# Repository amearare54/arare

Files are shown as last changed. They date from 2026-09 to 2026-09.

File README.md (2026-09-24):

<p align="center">
  <picture>
    <source media="(prefers-color-scheme: dark)" srcset="docs/readme-logo-white.png">
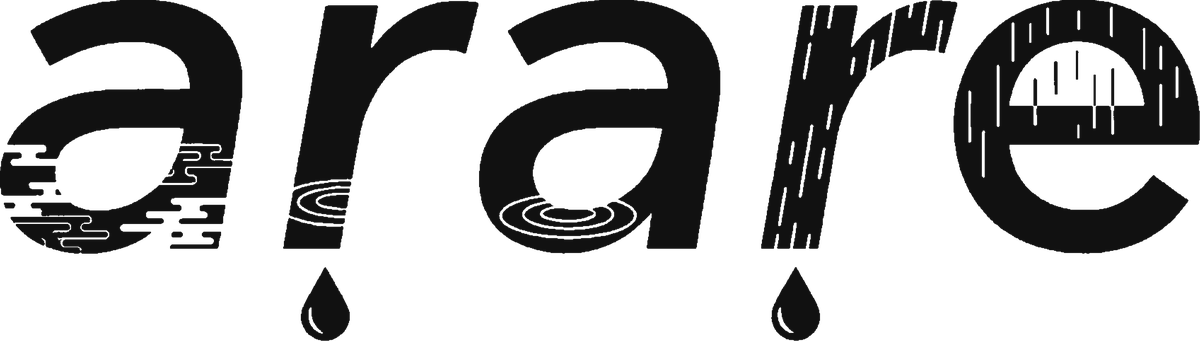
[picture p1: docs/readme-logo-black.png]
arare
    
  </picture>
</p>

<p align="center">
  左右分割・完全無線のロープロファイルキーボードです。<br>
  右手にトラックボール、左手にスティックを載せていて、<br>
  ホームポジションから手を大きく動かさないまま、打つ・指す・回すができます。
</p>

<p align="center">
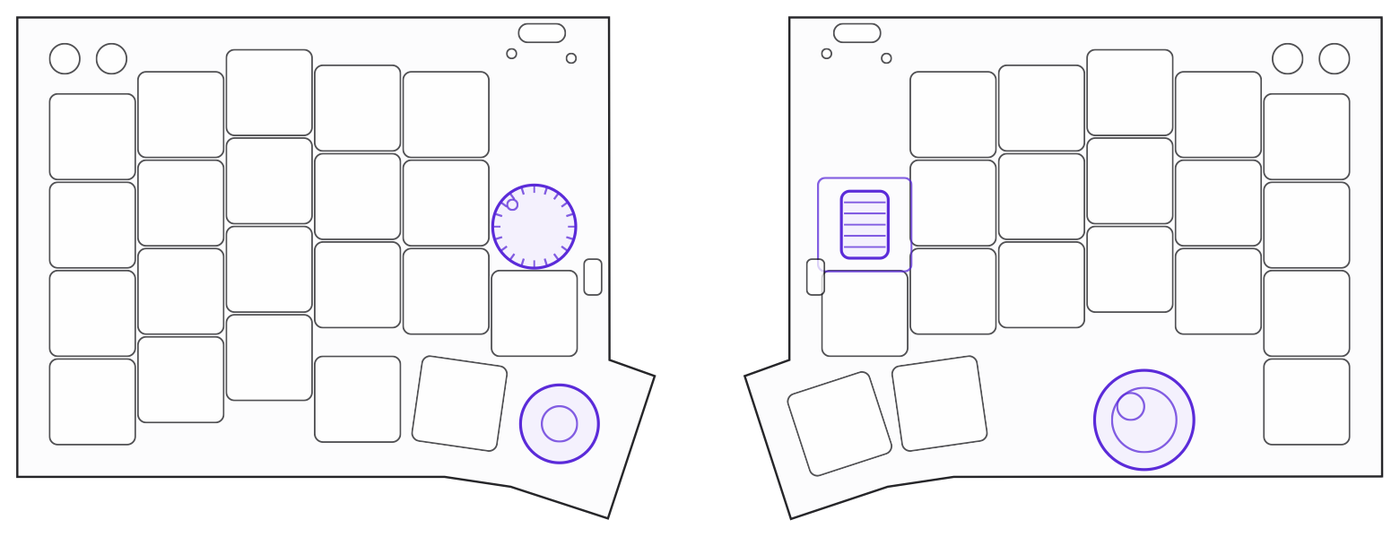
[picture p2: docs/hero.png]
arare 本体を上から見た図。左手側にノブとスティック、右手側にホイールとトラックボール
  
</p>

## 取扱説明書・カラーシミュレーター・arare Studio

ブラウザで開くだけの3つのページです。**アカウント登録もインストールも要りません。実機が手元になくても開けます。**

<div align="center">
<table>
<tr>
<td align="center" width="33%">
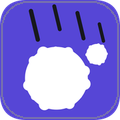
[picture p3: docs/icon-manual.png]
<br>
<a href="https://amearare54.github.io/arare/manual.html"><b>MANUAL</b></a><br>
どんなキーボードか知る
</td>
<td align="center" width="33%">
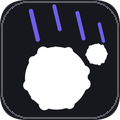
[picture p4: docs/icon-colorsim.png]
<br>
<a href="https://amearare54.github.io/arare/colorsim.html"><b>COLOR SIMULATOR</b></a><br>
色を決めるとき
</td>
<td align="center" width="33%">
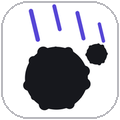
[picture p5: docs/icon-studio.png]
<br>
<a href="https://amearare54.github.io/arare/"><b>STUDIO</b></a><br>
キーを変えたくなったら
</td>
</tr>
</table>
</div>

> [!TIP]
> リンクが開けないときは、こちらから直接どうぞ。
> MANUAL <https://amearare54.github.io/arare/manual.html> ／
> COLOR SIMULATOR <https://amearare54.github.io/arare/colorsim.html> ／
> STUDIO <https://amearare54.github.io/arare/>
>
> arare Studio で実機につないで書き換える機能だけ、Chrome / Edge が必要です。
> 取扱説明書は開いたときに短い演出（4.6秒）が流れますが、クリックなどでいつでも飛ばせます。

ZMK の設定・ピン割当・ビルドを見に来た方は [技術情報](#技術情報) へどうぞ。

## arare でできること

| | できること |
|---|---|
| 右手・トラックボール | &#216;19 mm の光学センサー式。指で転がしてポインタを動かします。 |
| 右手・ホイール | 軸は左右方向で、前後に転がします（マウスのスクロールホイールと同じ向き）。出荷時は回すとページ送り、押し込みで ⌘V（貼り付け）。 |
| 左手・ノブ | 軸は上向きで、ボリュームつまみのように水平に回します。出荷時は回すと拡大 / 縮小（⌘+ / ⌘-）、押し込みで &#8679;&#8984;V。 |
| 左手・スティック | トラックパッドの代わりとして載せています。2 本指・3 本指でするような操作を、親指ひとつでできるように、というつもりです。倒すとその向きのショートカットが出ます（出荷時は Mission Control とデスクトップの移動＝トラックパッドの 3 本指スワイプと同じ操作）。カーソルはトラックボールの担当です。押し込んでいるあいだは L3 レイヤーになります。 |
| 完全無線 | 左右それぞれに電池とマイコンがあり、間をつなぐケーブルがありません。残量はマイコンのランプが色で知らせます。 |
| ホットスワップ | Kailh Choc v2 互換のキースイッチを、はんだ付けなしで差し替えられます。 |
| キーマップ | ブラウザから何度でも変えられます（[arare Studio](https://amearare54.github.io/arare/)）。 |

## まず見てほしいもの

**1. 大きさと各部を見る** → [取扱説明書の「各部の名称」](https://amearare54.github.io/arare/manual.html#parts)

平面図・側面図・正面図に寸法を入れた総組立図を載せています。コンセプト、はじめかた、出荷時のキーマップ、名前の由来、仕様・お手入れ・安全にお使いいただくために、なども入っています。

**2. 色を決める** → [カラーシミュレーターを開く](https://amearare54.github.io/arare/colorsim.html)

ケースは3Dプリントなので、部品ごとに色を選べます。実機と同じ3Dデータをブラウザに載せていて、クリア樹脂の見えかたも再現します。EXPLODE で分解図、AUTO でゆっくり回しながら確かめられます。

**3. キー配列を見る** → [arare Studio を開く](https://amearare54.github.io/arare/)

実機がなくても、配置図の上でキーの割り当てを触ってみられます。

## 使いはじめる

1. **電源を入れる** — 左右それぞれの側面にあるスライドスイッチを内側（ON）へ。左右とも忘れずに。
2. **パソコンとつなぐ** — Bluetooth の一覧から `arare` を選びます。一覧に出るのは右手側だけで、左手側は右手側と自動でつながります。
3. **キーの割り当てを変える** — 書き換える前に、右手の外側のタクトスイッチ（UNLOCK）を一回押します。→ [arare Studio](https://amearare54.github.io/arare/)

### ランプの見かた

USB-C のとなりに、同じ大きさの小さな穴が2つあります。片方がマイコン基板のリセットスイッチ、もう片方がランプです（どちらがどちらかは [取扱説明書の各部の名称](https://amearare54.github.io/arare/manual.html#parts) の図で確かめられます）。

ランプは電池残量を色で知らせます。ふだんは消えています。

| 色 | 残量 |
|---|---|
| 緑 | 60 % 以上 |
| 橙 | 20 % より上、60 % 未満 |
| 赤 | 20 % 以下 |

電源を入れたときと、しばらく置いてから使いはじめたときに 1.5 秒だけ点きます。残量が 20 % 以下になると赤く2回点滅して以降5分ごと、10 % 以下になると赤く3回点滅して以降2分ごとに知らせます。**点滅するのは使っているあいだだけで、置きっぱなしのときと充電中は光りません。** USB-C をつないでいるあいだは、残量の色が点いたままになります。

> [!TIP]
> つながらないとき、充電のしかた、接続先の切り替えは、[取扱説明書の「はじめかた」](https://amearare54.github.io/arare/manual.html#start) にまとめています。

## 仕様

| 項目 | 内容 |
|---|---|
| 方式 | 左右分割・Bluetooth LE 接続（ZMK ファームウェア） |
| キー数 | 実キー40（左21／右19）＋エンコーダー押し込み2／スティック押し込み1／タクトスイッチ4（計47ポジション） |
| 本体サイズ | 片手あたり 122.1 &#215; 96.1 mm ／ 高さ 23.8 mm（右）・28.1 mm（左・ノブ含む） |
| キーピッチ | 17 &#215; 17 mm |
| キースイッチ | Kailh Choc v2 互換・ホットスワップ |
| ポインティング | 19 mm トラックボール（光学センサー・PAW3222）／ TMR 磁気式スティック |
| ロータリー | 縦型ノブ（左・水平に回す）／ 横型ホイール（右・前後に転がす）各1、押し込み付き |
| マイコン | Seeed XIAO nRF52840 &#215;2（技適取得済みモジュール・central は右手） |
| 電源 | リチウムポリマー電池（左右各1）／ USB-C 充電 |
| ケース | 3Dプリント・ガスケットマウント構造 |
| 対応 | Bluetooth LE キーボードとして動作する機器（macOS / Windows / iOS / iPadOS / Android など） |
| 編集ツール | arare Studio（ブラウザ）／ ZMK Studio 互換 |

## このリポジトリにあるもの

| もの | 場所 | 条件 |
|---|---|---|
| 3つのページの実体 | [`docs/`](docs/) | 公開 |
| ファームウェア（ZMK設定） | [`config/`](config/) | 公開 |
| 電池残量ランプの自前モジュール | [`src/battery_led.c`](src/battery_led.c) / [`Kconfig`](Kconfig) / [`CMakeLists.txt`](CMakeLists.txt) | 公開 |
| ケース・プレート・ノブ等の3Dプリントデータ | [`model/case/`](model/case/) | 個人使用のみ |
| ロゴ（SVG / PNG / DXF / STL） | [`model/logo/`](model/logo/) | 個人使用のみ |

> [!IMPORTANT]
> `model/` の3Dデータとロゴは、個人使用のみにとどめてください。再配布・商用利用はご遠慮ください（→ [model/README.md](model/README.md)）。
> カラーシミュレーターに埋め込まれている3Dデータも同じ条件です。

**まだ公開していないもの**

- 基板データ（KiCad / ガーバー）
- キーキャップの3Dデータ

基板データが非公開のため、ここに公開しているデータだけで1台を組み上げることはできません。

**これからやること**

- DYA Studio のフル対応
- 深いスリープ（現在は無効）

理由は [技術情報](#技術情報)の「いまできないこと」に書いています。

## 技術情報

- ZMK v0.3.0 / ボードは `seeeduino_xiao_ble` &#215;2、central = 右手
- マトリクスは charlieplex 6線
- トラックボールは PAW3222。ドライバは sekigon-gonnoc/zmk-driver-paw3222（torabo-tsuki ブランチ）
- ZMK Studio 対応（central = 右手に USB 接続して <https://zmk.studio/> でも使えます）。タクトSW は左外側・左内側・右内側＝Bluetooth の接続先 1〜3、右外側＝アンロック
- ピン割当とマトリクス定義は、非公開の基板データ（KiCad）と機械照合しています

### ビルドと書き込み

1. push すると GitHub Actions がビルドします（`arare_R`＝Studio snippet 付き / `arare_L` / `settings_reset`）
2. Actions の Artifacts から UF2 をダウンロードします
3. XIAO を BOOT モード（リセット2度押し）にすると、USB ドライブとして見えます
4. UF2 をそこにコピーすると書き込まれます

書き込みは左右それぞれに必要です。

> [!WARNING]
> 設定がおかしくなったときは、左右それぞれに `settings_reset` を書き込んでから、`arare_R` / `arare_L` を書き直してください。`settings_reset` を書き込んだままではキーボードとして動きません。

<details>
<summary>ピン割当とマトリクス</summary>

| | 左手 (peripheral) | 右手 (**central**) |
|---|---|---|
| ボード | seeeduino_xiao_ble | seeeduino_xiao_ble |
| マトリクス | charlieplex 6線 (M0=D0 M1=D1 M2=D6 M3=D7 M4=D8 M5=D9) | charlieplex 6線 (M0..M5=D0..D5) |
| エンコーダ | EC12縦 (D2/D3) 押込=Shift+Cmd+V | CKW12横 (D6/D7) 押込=Cmd+V |
| ポインタ | スティック アナログXY (AIN2/AIN3)＝ジェスチャー専用（右手の `joy_gesture` が処理）＋ 押込=D10直結キー（`&mo 3`） | PAW3222 (spi1: SCK=P1.13 SDIO=P1.14 CS=P1.15 MOTION=P0.09) |

スティックのアナログXYは `CONFIG_ZMK_BATTERY_REPORTING` と SAADC を取り合います。ZMK 本体の電池ドライバは oversampling=4 が固定で、併用すると SAADC が止まります。`arare_saadc_fix.dtsi` が本体の `&vbatt` を無効にし、oversampling=0 の arare 版ノードへ `zmk,battery` を向け替えることで両立させています（`arare_tuning_L.dtsi` から include）。

電池残量ランプは `CONFIG_ARARE_BATTERY_LED` で有効にする自前モジュールです（`zephyr/module.yml` から `Kconfig` と `CMakeLists.txt` を読み込み、`src/battery_led.c` をビルドします）。しきい値・点灯時間・警告間隔は `Kconfig` で変えられます。

</details>

<details>
<summary>いまできないこと（フェーズ2・既知の制約）</summary>

- **DYA Studio フル対応**: キーマップ編集は公式 ZMK Studio 対応のまま DYA Studio からも使えます。トラックボール調整等のフル機能には cormoran/zmk フォーク＋モジュール4点が必要です（experimental 宣言あり）。
- **深いスリープ（`CONFIG_ZMK_SLEEP`）**: charlieplex が割込を持てず復帰不能なため、無効のままです。電源は物理スイッチで切ります。

</details>

## 名前のこと

「感謝感激雨あられ」の **あられ** から取りました。世に出ている良いキーボードの設計を参考にさせていただいたことへの**感謝**と、使ってくださる方に**感激**してほしいという願いを、そのまま名前にしています。

ロゴの文字には、和の気象の意匠が彫ってあります。霞・雨・波紋・しずく。遠目にはただの文字ですが、近づくと天気が見えてきます。表記は小文字の arare で通しています。

## 利用条件

- `config/` `src/` `Kconfig` `CMakeLists.txt` `zephyr/` のファームウェアと `docs/` のページ … 公開しています。参照や、ご自身の arare 用のビルドにお使いいただけます
- `model/case/` `model/logo/` の3Dデータとロゴ … 個人使用のみ。再配布・商用利用はご遠慮ください（→ [model/README.md](model/README.md)）
- 基板データ（KiCad / ガーバー）、キーキャップの3Dデータ … 非公開です

気づいたことや質問は Issues へどうぞ。

---

<p align="center">
  <a href="https://amearare54.github.io/arare/manual.html">MANUAL</a> ・
  <a href="https://amearare54.github.io/arare/colorsim.html">COLOR SIMULATOR</a> ・
  <a href="https://amearare54.github.io/arare/">STUDIO</a>
</p>

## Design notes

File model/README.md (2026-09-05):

> [!CAUTION]
> ここに公開している3Dデータは個人使用のみにとどめてください。
> 再配布・商用利用はご遠慮ください。

# arare 3Dプリントデータ

ケース・プレート・ノブ等の3Dデータです。**基板データ（KiCad/ガーバー）とキーキャップは非公開です。**

## ファイル一覧（case/）

| ファイル | 内容 |
|---|---|
| top plate L / R | トッププレート（Rはトラックボールケース一体） |
| middle plate L 1〜3 / R 1〜2 | ミドルプレート（キースイッチホルダー、厚1.2mm）。**エンコーダの有る無しなどに合わせて選べます** |
| bottom plate L / R | ボトムプレート（磁石ポケットΦ6×3・ゴム足座つき） |
| gasket mount L / R | ガスケットマウント |
| vertical rotary encoder 1 / 2 | 左手・縦型エンコーダ（EC12）用ノブまわり |
| horizontal rotary encoder 1 | 右手・水平エンコーダ（CKW12）用なぞりホイール |
| parts 1〜4 | 小物（タクトSWキャップ・押し棒・電源SWツマミ等） |

## ロゴ（logo/）

「arare（あられ）」に掛けて、文字ごとに和の気象モチーフ（霞・雨・波紋・しずく）が入っています。

| ファイル | 内容 |
|---|---|
| arare_logo.svg | ★マスター。ベクター・無次元（`fill="currentColor"`） |
| arare_logo_黒 / 白.png | ラスタ版（6788×1928px・背景透過） |
| arare_logo_{R 13.324mm / L 16.179mm}.svg / .dxf | 基板実寸のベクター（DXFはCAD用・y上向き） |
| arare_logo_{R/L}_*_emboss0.6mm.stl | 3Dプリント用エンボス（厚0.6mm・watertight） |

## 印刷設定の目安（Bambu Lab A1 mini / eSUN PLA+ で実績）

- **ケース・プレート類（このフォルダの大物）: 0.4mmノズル**、壁4ライン、Arachne有効
- 小物（parts・エンコーダノブ）: 0.2mmノズルだと細部（0.5mm級フィーチャ）の再現性が上がる
- ビルドプレートは Cold PEI 想定

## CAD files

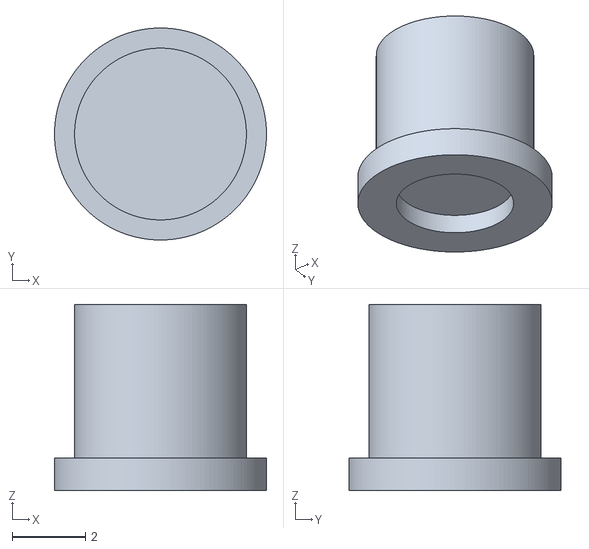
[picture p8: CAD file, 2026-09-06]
model/case/parts 1.stl
5.80 x 5.80 x 5.10

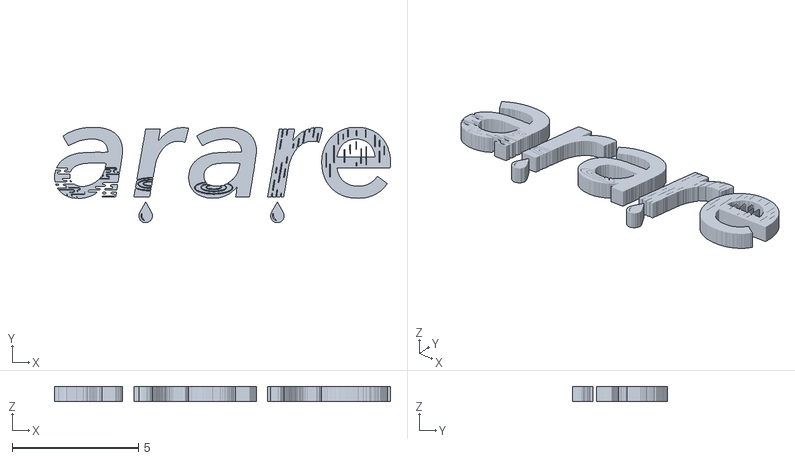
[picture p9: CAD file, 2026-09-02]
model/logo/arare_logo_R_13.324mm_emboss0.6mm.stl
13.3 x 3.78 x 0.6

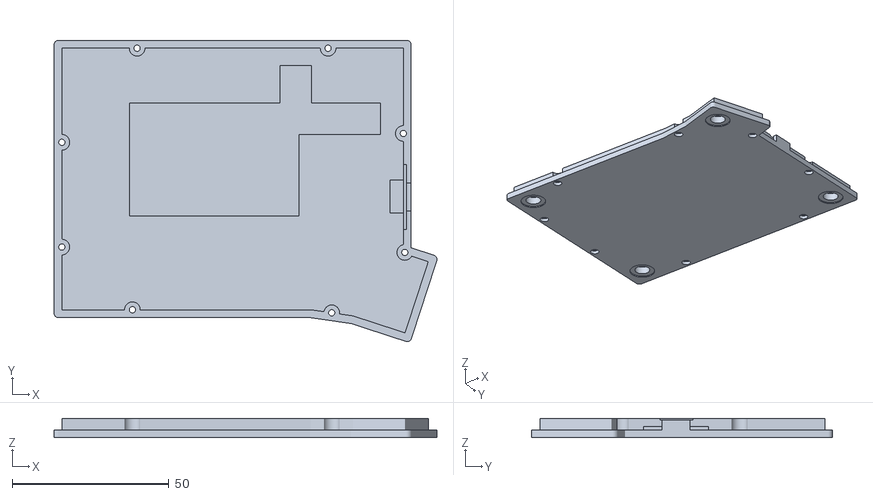
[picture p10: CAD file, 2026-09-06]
model/case/bottom plate L.stl
122.1 x 96.1 x 6.10

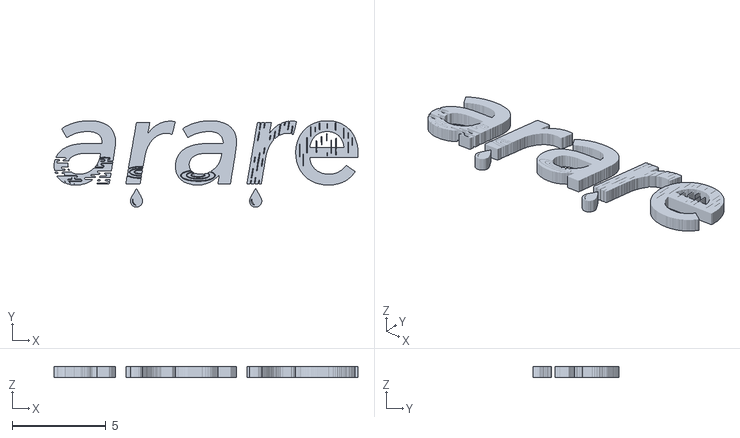
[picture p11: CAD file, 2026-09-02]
model/logo/arare_logo_L_16.179mm_emboss0.6mm.stl
16.2 x 4.60 x 0.6

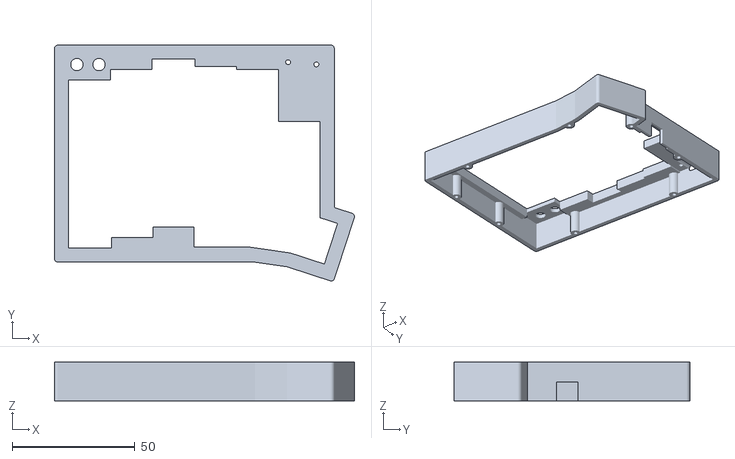
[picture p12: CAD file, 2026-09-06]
model/case/top plate L.stl
122.1 x 96.1 x 15.7

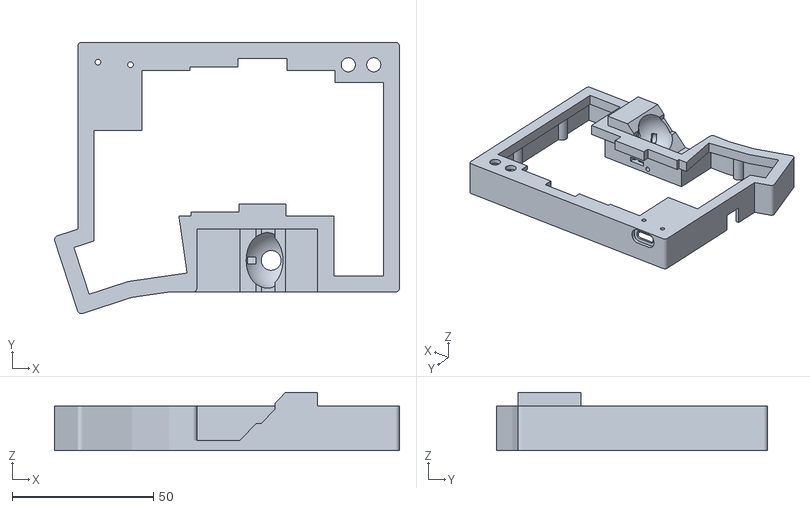
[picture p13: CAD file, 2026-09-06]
model/case/top plate R.stl
122.1 x 96.1 x 20.6

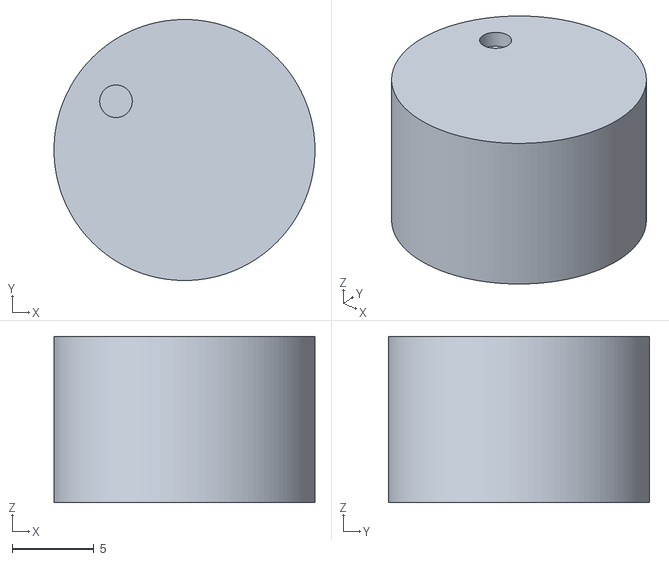
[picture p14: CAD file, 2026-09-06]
model/case/vertical rotary encoder 1.stl
16.0 x 16.0 x 10.2

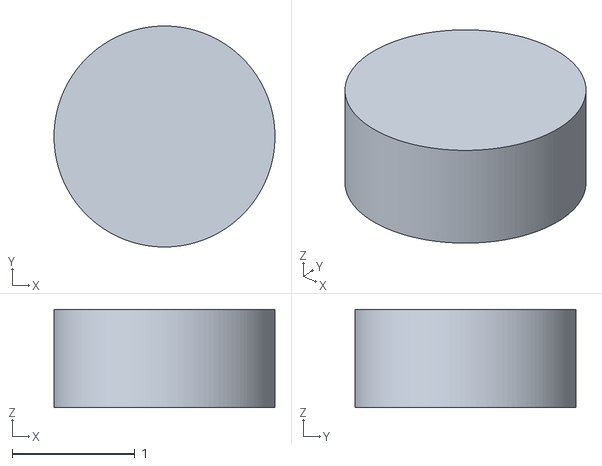
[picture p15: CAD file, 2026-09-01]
model/case/vertical rotary encoder 2.stl
1.80 x 1.80 x 0.8

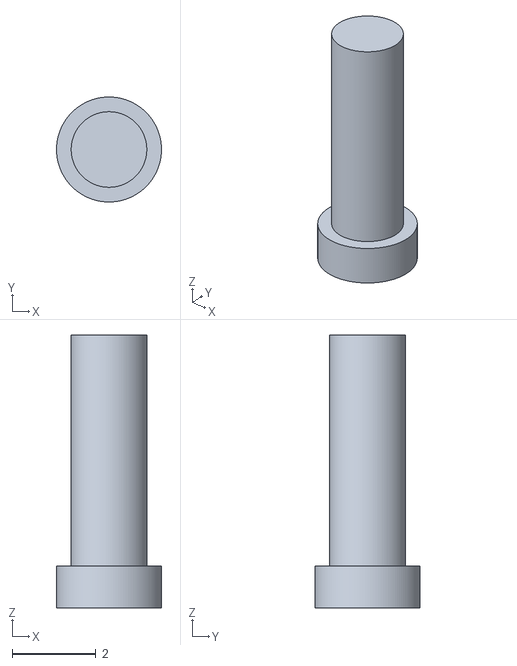
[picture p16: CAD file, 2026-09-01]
model/case/parts 2.stl
2.50 x 2.50 x 6.50

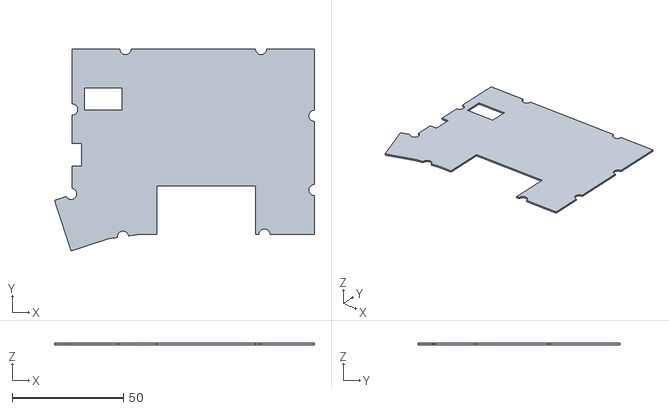
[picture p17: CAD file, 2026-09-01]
model/case/gasket mount R.stl
116.8 x 90.8 x 0.8

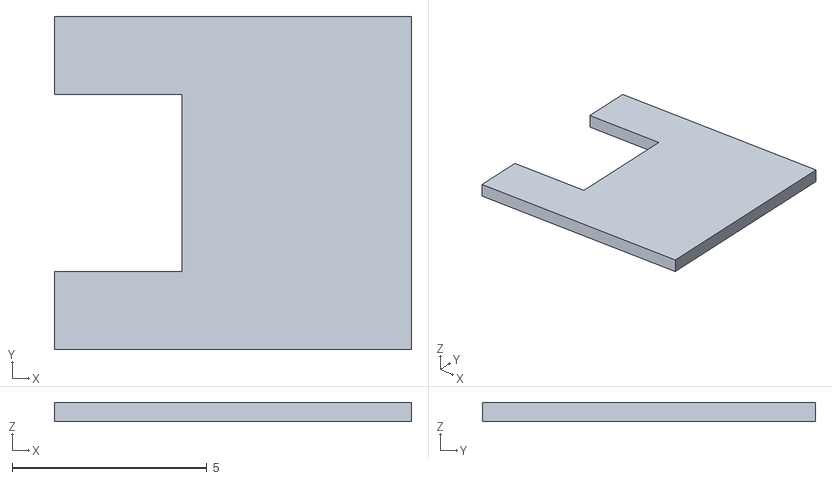
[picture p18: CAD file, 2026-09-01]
model/case/parts 4.stl
9.18 x 8.55 x 0.5

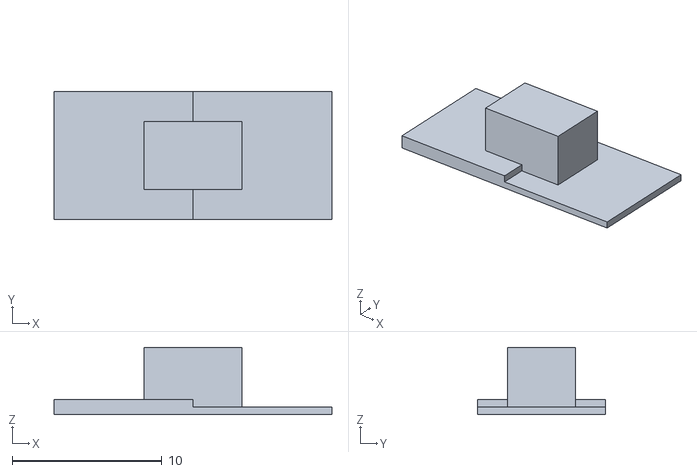
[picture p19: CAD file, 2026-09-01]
model/case/parts 3.stl
18.5 x 8.55 x 4.50

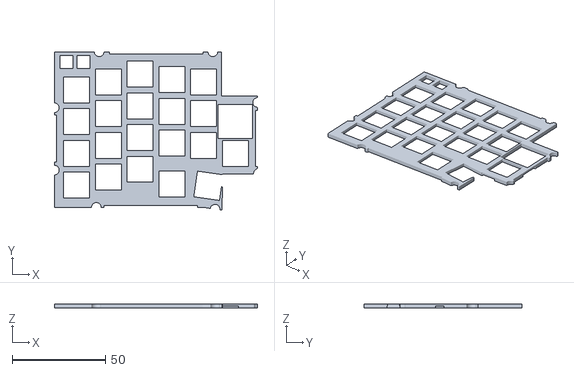
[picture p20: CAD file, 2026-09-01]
model/case/middle plate L 2.stl
108.7 x 84.7 x 2.20

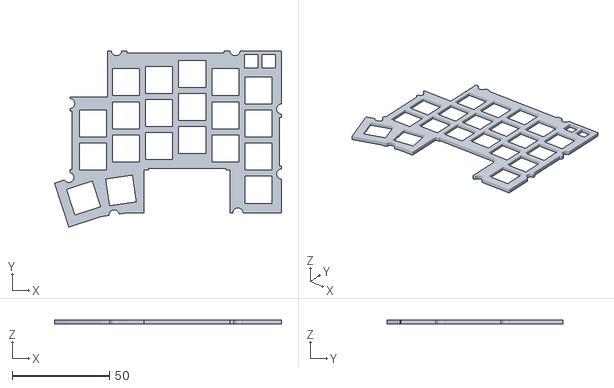
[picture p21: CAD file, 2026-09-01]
model/case/middle plate R 1.stl
116.6 x 90.5 x 2.20

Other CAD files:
model/logo/arare_logo_R_13.324mm.dxf
model/logo/arare_logo_L_16.179mm.dxf
model/case/bottom plate R.stl
model/case/middle plate L 3.stl
model/case/gasket mount L.stl
model/case/horizontal rotary encoder 1.stl
model/case/middle plate L 1.stl
model/case/middle plate R 2.stl

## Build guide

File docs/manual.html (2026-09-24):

SKIP

ManualStudioColor Sim

Owner’s Manual · 取扱説明書

# 打つ・指す・回す・スクロールする。 手をホームポジションから動かさないまま、ぜんぶ、そこでできる。

arare をお迎えいただき、ありがとうございます。このページは、はじめて電源を入れるところから、キーマップを自分好みに変えるところまでをひととおり案内する取扱説明書です。

Layout

左右分割 40キー
122.1 × 96.1 mm / 片手

Wireless

Bluetooth LE
ZMK ファームウェア

Pointing

19 mm トラックボール
スティック

Rotary

ノブ & ホイール
押し込み付き

01Concept

## 「持ち替えない」ためのキーボード

文字を打つ、カーソルを動かす、スクロールする、音量を変える。ふだんの作業でいちばん時間を食っているのは、そのあいだの持ち替えです。arare は、その持ち替えをなくすことだけを目的に設計した、左右分割・完全無線のロープロファイルキーボードです。

右手の親指のすぐ先に 19 mm のトラックボール、人差し指側に前後に転がすホイール。左手には水平に回すノブとスティック。キーは 40 個に絞り、足りないぶんはレイヤーで補います。指を広げる距離が短いほど、手は疲れません。

左手のスティックはトラックパッドの代わりです。トラックパッドのいちばんいいところは、2 本指・3 本指で直感的に操作できることだと考えていて、それを親指ひとつで引き受けてもらうつもりで載せています。

Split & Wireless

#### 左右が独立して、ケーブルがない

左右それぞれに電池とマイコンを積んでいるので、間をつなぐケーブルがありません。肩幅に合わせて好きな位置・好きな角度に置けます。

Low profile

#### 薄いキーで、手首が反らない

Kailh Choc v2 のロープロファイル軸と 17 mm ピッチ。天面が低いので、パームレストなしでも手首が起きたままになりません。

Hot swap

#### キースイッチは工具なしで交換できる

ホットスワップソケット式です。押し心地が気に入らなければ、はんだ付けなしで別の Choc v2 軸に差し替えられます。

Yours to change

#### キーの中身は、あとから何度でも

キーマップもトラックボールの速さも、ブラウザから変えられます（arare Studio）。買ったときの配列に縛られません。

02Parts & functions

## 各部の名称とはたらき

左右で役割が違います。右手側がホスト（パソコン）とつながる側で、左手側は右手側にぶら下がる形で接続されます。パソコンの Bluetooth 設定に出てくるのは右手側だけです。

Fig.1 ケースと基板の実データから起こした配置図（上から見た図・単位 mm）

各部 | 位置 | はたらき
トラックボール | 右 | 指で転がしてポインタを動かします。Ø19 mm・光学センサー式。
ホイール（横型エンコーダー） | 右 | 軸は左右方向。指で前後に転がします（マウスのスクロールホイールと同じ向き）。回すとページ送り、押し込みは ⌘V（貼り付け）です。
ノブ（縦型エンコーダー） | 左 | 軸は上向き。ボリュームつまみのように水平に回します。回すと拡大 / 縮小（⌘+ / ⌘-）、押し込みは ⇧⌘V（書式なしペースト）です。
スティック | 左 | トラックパッドの代わりです。2 本指・3 本指でするような操作を、親指ひとつでできるようにと載せています。倒すと、その向きのショートカットが出ます——出荷時は Mission Control とデスクトップの移動（macOS のトラックパッドの 3 本指スワイプと同じ操作）です。カーソルは動きません（それはトラックボールの担当です）。押し込むと L3 レイヤーになります。倒しはじめの重さと、どの向きに何を出すかは arare Studio から変えられます。
タクトスイッチ（外側） | 左右 | 左は Bluetooth の接続先 1 への切り替え。右は UNLOCK で、Studio からキーを書き換える前にいちど押します。
タクトスイッチ（内側） | 左右 | Bluetooth の接続先の切り替え。左が 2、右が 3 です。
電源スイッチ | 左右 | 内側の側面にあるスライドスイッチ。左右それぞれに付いています。
リセットスイッチ・ライトの穴 | 左右 | USB-C のとなりに小さな穴が 2 つ（Ø1.86 mm・左右とも同じ大きさ）。マイコン基板のリセットスイッチとランプが、ここから見えます。ファームウェアを書き込むときに使います。ランプは電池残量を色で知らせます（下の「ランプの見かた」）。
USB-C | 左右 | 充電とファームウェアの書き込みに使います。

### サイズ

片手あたりの外形は 122.1 × 96.1 mm。文庫本より一回り小さいくらいです。左右が独立しているので、置く幅も角度も自由に決められます。高さは右手側が 23.8 mm、左手側はノブのぶんだけ高くなって 28.1 mm です。

下の一枚に、上から・横から・手前からの三面図と寸法をまとめました。3 つの図はすべて同じ 3D データから同じ縮尺で起こしています。

Fig.2 総組立図 — 平面図・側面図・正面図と寸法（単位 mm）

03Getting started

## はじめかた

1. 電源を入れる左右それぞれの側面にあるスライドスイッチを、内側（ON）へ動かします。左右とも忘れずに。
2. パソコンとつなぐパソコンの Bluetooth 設定を開き、一覧に出てくる arare を選びます。左手側は右手側と自動でつながるので、パソコン側の操作は一度だけです。
3. つながらないときはいちど両側の電源を切り、右手側 → 左手側の順に入れ直します。それでも見つからないときは、左手の外側のタクトスイッチ（BT1）を押して、接続先を 1 に戻してください。タクトスイッチを押すと接続先が切り替わります。
4. 充電するUSB-C ケーブルをつなぐと充電されます。左右は別々の電池なので、片側ずつ充電してください。充電しながら使うこともできます。 残量はパソコン側の Bluetooth の表示で確認します。左右とも残量を報告していて、右手側が左手側のぶんもまとめて送っています。
5. キーを自分用に変えるarare Studio をブラウザで開きます。書き換える前に、右手の外側のタクトスイッチ（UNLOCK）を一回押してください。

### ランプの見かた

USB-C のとなりの小さな穴から、マイコン基板のランプが見えます。 電池残量を色で知らせます。ふだんは消えていて、知らせるべきときだけ光ります （点けっぱなしにすると、そのぶん電池が減るためです）。

色 | 残量
緑 | 60 % 以上
橙 | 20 % より上、60 % 未満
赤 | 20 % 以下

光るとき | 光りかた
電源を入れたとき | 残量の色が 1.5 秒つきます
しばらく置いたあと、また使いはじめたとき | 同じく 1.5 秒つきます
残量が 20 % 以下になったとき | その場で赤く 2 回点滅。以降、使っているあいだ 5 分ごとに知らせます
残量が 10 % 以下になったとき | 赤く 3 回点滅。以降 2 分ごとに知らせます
USB-C をつないでいるあいだ | 残量の色がつきっぱなしになります。緑に変われば充電が進んだ合図です

眠っているあいだと充電中は、残量が少なくても催促しません。 パーセントの数字で見たいときは、パソコン側の Bluetooth の表示で確認できます。

### 接続先を切り替える

Bluetooth の接続先は 5 台まで覚えられます。出荷時は左手の外側・内側と右手の内側のタクトスイッチで、接続先 1〜3 を切り替えます。4 台目・5 台目を使う方や、ほかのキーで切り替えたい方は、Studio の「接続」画面から好きなキーに割り当ててください。

04Default keymap

## 出荷時のキーマップ

レイヤーは 4 つです。fn1 を押しているあいだが記号、fn2 を押しているあいだが数字と矢印。US 配列のパソコンにつないだ状態で、キーに書いてあるとおりの文字が出ます。

L3 はスティックを押しているあいだ有効になるマウス用です。J・L が左・右クリック、K が ⇧⌘V（書式なしで貼り付け）になります。

arare Studio を開く → (https://amearare54.github.io/arare/)

L0 Base L1 Sym L2 Num L3 Mouse ・印はひとつ下のレイヤーがそのまま出るキーです

Fig.3 出荷時キーマップ（実際のファームウェア設定から生成）

操作 | 出荷時の割り当て
ノブを回す（左） | 拡大 / 縮小（⌘+ / ⌘-）
ホイールを回す（右） | ページ送り（PageUp / PageDown）
ノブを押す（左） | ⇧⌘V
ホイールを押す（右） | ⌘V（貼り付け）
ホイールの下のキー（右） | ⌘C（コピー）
スティックを押す（左） | 押しているあいだ L3（J・L が左・右クリック、K が ⇧⌘V）
スティックを倒す（左） | Mission Control / App Exposé / デスクトップの移動
A を長押し | ⌃
英数 を長押し | ⇧
Ctrl を長押し | ⌥
タクトスイッチ 4 つ | Bluetooth の接続先 1〜3 の切り替えと UNLOCK
fn2 ＋ Y / U | ⇧⌘3 / ⇧⌘4（スクリーンショット）
fn2 ＋ ⏎ / ⌫ | ⌃← / ⌃→（デスクトップの移動）
fn1 ＋ タクトスイッチ | F13〜F16（Mac 側でアプリの起動に割り当てられます）

05Color simulator

## 色を決めてから、刷る

ケースは 3D プリントなので、部品ごとに色を選べます。ただ「白と黒、どっちが好きか」は、実物を並べてみないとなかなか決まりません。そのための道具が COLOR SIMULATOR です。ブラウザで開くだけで、アプリも会員登録も要りません。

Color simulator

### arare COLOR SIMULATOR

実機とおなじ 3D データを、そのままブラウザに載せています。左右まるごと、部品ひとつひとつの色を変えながら回して確かめられます。

- 天板・底板・キーキャップ・ノブなど、部品ごとに色を指定
- クリア（透明）樹脂の見えかたも再現
- EXPLODE — 分解図にして、内部の重なりを確認
- AUTO — ゆっくり回しながら全方向から眺める

COLOR SIMULATOR を開く → (https://amearare54.github.io/arare/colorsim.html)

amearare54.github.io/arare/colorsim.html

CLEAR

per-part color · explode · auto

06arare Studio

## キーの中身を、自分で決める

arare Studio は、arare 専用のキーマップエディタです。画面に出るのは実物とおなじ配置図で、親指キーの角度まで基板の実データから起こしています。押したいキーをクリックして、割り当てたい動作を選ぶ。それだけです。

使いかたは 2 とおりあります。LIVE はキーボードを直接つないで、クリックした瞬間に実機へ反映する方法（Chrome / Edge が必要です）。FORGE は設定ファイルを書き出して、ファームウェアをビルドし直す方法です。ふだんの調整は LIVE で足ります。

Keymap editor

### arare Studio

ブラウザだけで動きます。設定はお使いのブラウザの中に保存されるので、他の人と混ざることはありません。

- レイヤーは 10 層まで追加・複製・削除（取り消しも可）
- Mod-Tap、コンボ（同時押し）、長押し時間の調整
- トラックボールの速さ・加速・精密モード・スクロール
- 接続先ごとに別のキーマップ（Mac と Windows で切り替え）
- US ⇄ JIS 配列の切り替え
- 名前をつけて設定を保存（プロファイル）

arare Studio を開く → (https://amearare54.github.io/arare/)

amearare54.github.io/arare/

click a key · live to device

書き換える前に UNLOCK。安全のため、キーボードは通常「書き換え禁止」の状態になっています。右手の外側のタクトスイッチ（UNLOCK）を一回押してから、Studio の接続ボタンを押してください。
なお UNLOCK のキーを全部つぶさないでください。押せる UNLOCK がひとつもなくなると、ファームウェアを書き込み直すまで編集できなくなります。

07The name

## 名前のこと

このキーボードには、たくさんの先人の設計が入っています。分割の考えかた、親指まわりの置きかた、トラックボールの収めかた。世に出ている「いいキーボード」のいいところを、参考にさせていただいて組み上げました。まず、そのことへの感謝があります。

そして、使ってくださる方に、毎日がすこし豊かになったと感激してほしい。名前は、その二つをそのまま日本語のことばから借りています。

感謝 感激 雨あられ → arare

ロゴにも同じことを込めました。文字のひとつひとつに、和の気象の意匠が彫ってあります。空にかかる霞、降る雨、水面に広がる波紋、そして落ちるしずくが二つ。遠目にはただの文字ですが、近づくと天気が見えてきます。

Fig.4 ロゴに彫られた意匠

08Specifications & care

## 仕様とお手入れ

方式 | 左右分割・Bluetooth LE 接続（ZMK ファームウェア）
キー数 | 47 ポジション（実キー 40／エンコーダー押し込み 2／スティック押し込み 1／タクトスイッチ 4）
本体サイズ | 片手あたり 122.1 × 96.1 mm ／ 高さ 23.8 mm（右）・28.1 mm（左・ノブ含む）
キーピッチ | 17 × 17 mm
キースイッチ | Kailh Choc v2 互換・ホットスワップ（出荷時：静音リニア 40 gf）
ポインティング | 19 mm トラックボール（光学センサー）／ TMR 磁気式スティック
ロータリー | 縦型ノブ（左・水平に回す）／ 横型ホイール（右・前後に転がす）各 1、押し込み付き
マイコン | Seeed XIAO nRF52840（技適取得済みモジュール）
電源 | リチウムポリマー電池（左右各 1）／ USB-C 充電
ケース | 3D プリント・ガスケットマウント構造
対応 OS | Bluetooth LE キーボードとして動作する機器（macOS / Windows / iOS / iPadOS / Android など）
編集ツール | arare Studio（ブラウザ）／ ZMK Studio 互換

### お手入れ

キーのすき間のほこりは、やわらかい刷毛やエアダスターで払ってください。トラックボールとその受け皿は、乾いた布で拭くと転がりが戻ります。ケースは 3D プリントの樹脂なので、アルコールや溶剤は使わないでください。白く曇ることがあります。

### 安全にお使いいただくために

- 内部にリチウムポリマー電池が入っています。強い力で押す・落とす・分解することは避けてください。
- 電池がふくらんだ、熱をもつ、異臭がするなどの異常に気づいたら、ただちに使用をやめてご連絡ください。
- 直射日光の当たる車内など、高温になる場所に放置しないでください。
- 水や飲みものがかからないようにしてください。防水ではありません。
- 長期間使わないときは、電源スイッチを切って保管してください。
- 廃棄するときは、電池を取り外し、お住まいの自治体または回収拠点の案内に従ってください。

Keymap editor arare Studio キーマップとトラックボールの設定をブラウザで。実機につないで即反映もできます。 Color simulator arare COLOR SIMULATOR 部品ごとの色を3Dで確かめる。分解図とクリア樹脂の見えかたも。

arare — 取扱説明書

感謝感激雨あられ

入場をもう一度

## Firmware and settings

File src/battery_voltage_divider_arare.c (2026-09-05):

/*
 * arare — 電池電圧ドライバ（SAADCのオーバーサンプリングを無効化した版）
 *
 * ZMK v0.3.0 の app/module/drivers/sensor/battery/battery_voltage_divider.c を
 * MIT ライセンスのもとで複製し、compatible と oversampling だけを変更したもの。
 * 本家を fork せずに済ませるため、arare の設定リポジトリ側にドライバを持つ。
 *
 * 有効化: デバイスツリーで compatible = "arare,battery-voltage-divider" のノードを
 *   status = "okay" にし、chosen { zmk,battery = <そのノード>; } を向ける。
 *   本家の &vbatt は status = "disabled" にすること（二重定義を避ける）。
 *
 * Copyright (c) 2020 The ZMK Contributors
 * SPDX-License-Identifier: MIT
 */

#define DT_DRV_COMPAT arare_battery_voltage_divider

#include <zephyr/device.h>
#include <zephyr/devicetree.h>
#include <zephyr/drivers/gpio.h>
#include <zephyr/drivers/adc.h>
#include <zephyr/drivers/sensor.h>
#include <zephyr/logging/log.h>

#include "battery_common.h"

LOG_MODULE_REGISTER(arare_battery, CONFIG_ZMK_LOG_LEVEL);

struct io_channel_config {
    uint8_t channel;
};

struct bvd_config {
    struct io_channel_config io_channel;
    struct gpio_dt_spec power;
    uint32_t output_ohm;
    uint32_t full_ohm;
};

struct bvd_data {
    const struct device *adc;
    struct adc_channel_cfg acc;
    struct adc_sequence as;
    struct battery_value value;
};

static int bvd_sample_fetch(const struct device *dev, enum sensor_channel chan) {
    struct bvd_data *drv_data = dev->data;
    const struct bvd_config *drv_cfg = dev->config;
    struct adc_sequence *as = &drv_data->as;

    // Make sure selected channel is supported
    if (chan != SENSOR_CHAN_GAUGE_VOLTAGE && chan != SENSOR_CHAN_GAUGE_STATE_OF_CHARGE &&
        chan != SENSOR_CHAN_ALL) {
        LOG_DBG("Selected channel is not supported: %d.", chan);
        return -ENOTSUP;
    }

    int rc = 0;

#if DT_INST_NODE_HAS_PROP(0, power_gpios)
    // Enable power before sampling
    rc = gpio_pin_set_dt(&drv_cfg->power, 1);

    if (rc != 0) {
        LOG_DBG("Failed to enable ADC power GPIO: %d", rc);
        return rc;
    }

    // wait for any capacitance to charge up
    k_sleep(K_MSEC(10));
#endif // DT_INST_NODE_HAS_PROP(0, power_gpios)

    // Read ADC
    rc = adc_read(drv_data->adc, as);
    as->calibrate = false;

    if (rc == 0) {
        int32_t val = drv_data->value.adc_raw;

        adc_raw_to_millivolts(adc_ref_internal(drv_data->adc), drv_data->acc.gain, as->resolution,
                              &val);

        uint16_t millivolts = val * (uint64_t)drv_cfg->full_ohm / drv_cfg->output_ohm;
        LOG_DBG("ADC raw %d ~ %d mV => %d mV", drv_data->value.adc_raw, val, millivolts);
        uint8_t percent = lithium_ion_mv_to_pct(millivolts);
        LOG_DBG("Percent: %d", percent);

        drv_data->value.millivolts = millivolts;
        drv_data->value.state_of_charge = percent;
    } else {
        LOG_DBG("Failed to read ADC: %d", rc);
    }

#if DT_INST_NODE_HAS_PROP(0, power_gpios)
    // Disable power GPIO if present
    int rc2 = gpio_pin_set_dt(&drv_cfg->power, 0);

    if (rc2 != 0) {
        LOG_DBG("Failed to disable ADC power GPIO: %d", rc2);
        return rc2;
    }
#endif // DT_INST_NODE_HAS_PROP(0, power_gpios)

    return rc;
}

static int bvd_channel_get(const struct device *dev, enum sensor_channel chan,
                           struct sensor_value *val) {
    struct bvd_data *drv_data = dev->data;
    return battery_channel_get(&drv_data->value, chan, val);
}

static const struct sensor_driver_api bvd_api = {
    .sample_fetch = bvd_sample_fetch,
    .channel_get = bvd_channel_get,
};

static int bvd_init(const struct device *dev) {
    struct bvd_data *drv_data = dev->data;
    const struct bvd_config *drv_cfg = dev->config;

    if (drv_data->adc == NULL) {
        LOG_ERR("ADC failed to retrieve ADC driver");
        return -ENODEV;
    }

    int rc = 0;

#if DT_INST_NODE_HAS_PROP(0, power_gpios)
    if (!device_is_ready(drv_cfg->power.port)) {
        LOG_ERR("GPIO port for power control is not ready");
        return -ENODEV;
    }
    rc = gpio_pin_configure_dt(&drv_cfg->power, GPIO_OUTPUT_INACTIVE);
    if (rc != 0) {
        LOG_ERR("Failed to control feed %u: %d", drv_cfg->power.pin, rc);
        return rc;
    }
#endif // DT_INST_NODE_HAS_PROP(0, power_gpios)

    drv_data->as = (struct adc_sequence){
        .channels = BIT(0),
        .buffer = &drv_data->value.adc_raw,
        .buffer_size = sizeof(drv_data->value.adc_raw),
        /* ★ここが本家との唯一の実質差分。
         * 4(=16倍オーバーサンプリング)にすると Zephyr が SAADC の BURST を有効化し、
         * アナログスティックの複数チャネル読みと切り替わる際に END イベントが出なくなって
         * adc_read が K_FOREVER で固まる。詳細は arare_L.conf のコメント。
         * 代償: 平均化が無くなるぶん電池電圧の読みが本家よりノイジーになる。 */
        .oversampling = 0,
        .calibrate = true,
    };

#ifdef CONFIG_ADC_NRFX_SAADC
    drv_data->acc = (struct adc_channel_cfg){
        .gain = ADC_GAIN_1_6,
        .reference = ADC_REF_INTERNAL,
        .acquisition_time = ADC_ACQ_TIME(ADC_ACQ_TIME_MICROSECONDS, 40),
        .input_positive = SAADC_CH_PSELP_PSELP_AnalogInput0 + drv_cfg->io_channel.channel,
    };

    drv_data->as.resolution = 12;
#else
#error Unsupported ADC
#endif

    rc = adc_channel_setup(drv_data->adc, &drv_data->acc);
    LOG_DBG("AIN%u setup returned %d", drv_cfg->io_channel.channel, rc);

    return rc;
}

static struct bvd_data bvd_data = {.adc = DEVICE_DT_GET(DT_IO_CHANNELS_CTLR(DT_DRV_INST(0)))};

static const struct bvd_config bvd_cfg = {
    .io_channel =
        {
            DT_IO_CHANNELS_INPUT(DT_DRV_INST(0)),
        },
#if DT_INST_NODE_HAS_PROP(0, power_gpios)
    .power = GPIO_DT_SPEC_INST_GET(0, power_gpios),
#endif
    .output_ohm = DT_INST_PROP(0, output_ohms),
    .full_ohm = DT_INST_PROP(0, full_ohms),
};

DEVICE_DT_INST_DEFINE(0, &bvd_init, NULL, &bvd_data, &bvd_cfg, POST_KERNEL,
                      CONFIG_SENSOR_INIT_PRIORITY, &bvd_api);

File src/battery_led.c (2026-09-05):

/*
 * arare — 電池残量をマイコン(XIAO nRF52840)内蔵のRGB LEDで知らせる
 *
 * 方針:
 *   常時点灯はしない（電池を食うため）。見たいとき・知らせるべきときだけ光らせる。
 *     - 起動して最初に残量が読めたとき … 残量色を短く点灯
 *     - スリープ/アイドルから復帰したとき … 残量色を短く点灯
 *     - 残量が少ないとき … 使用中に限り、定期的に赤く点滅して充電を促す
 *     - 閾値を下向きに跨いだ瞬間 … その場で点滅して知らせる
 *     - USB接続中 … 残量色を点灯したまま（充電の進みが分かる。電源はUSB側）
 *
 * LEDはボード定義で ACTIVE_LOW。論理値で扱えば極性はZephyrが吸収する。
 * alias の割り当ては led0=赤 / led1=青 / led2=緑 で、青と緑が直感と逆順なので注意。
 */

#include <zephyr/kernel.h>
#include <zephyr/device.h>
#include <zephyr/drivers/gpio.h>
#include <zephyr/init.h>
#include <zephyr/logging/log.h>

#include <zmk/battery.h>
#include <zmk/activity.h>
#include <zmk/event_manager.h>
#include <zmk/events/battery_state_changed.h>
#include <zmk/events/activity_state_changed.h>

#if IS_ENABLED(CONFIG_ZMK_USB)
#include <zmk/usb.h>
#include <zmk/events/usb_conn_state_changed.h>
#endif

LOG_MODULE_REGISTER(arare_battery_led, CONFIG_ZMK_LOG_LEVEL);

#define LED_RED_NODE   DT_ALIAS(led0)
#define LED_BLUE_NODE  DT_ALIAS(led1)
#define LED_GREEN_NODE DT_ALIAS(led2)

#if !DT_NODE_EXISTS(LED_RED_NODE) || !DT_NODE_EXISTS(LED_GREEN_NODE)
#error "arare: このボードには led0 / led2 の alias がありません"
#endif

static const struct gpio_dt_spec led_red = GPIO_DT_SPEC_GET(LED_RED_NODE, gpios);
static const struct gpio_dt_spec led_green = GPIO_DT_SPEC_GET(LED_GREEN_NODE, gpios);
#if DT_NODE_EXISTS(LED_BLUE_NODE)
static const struct gpio_dt_spec led_blue = GPIO_DT_SPEC_GET(LED_BLUE_NODE, gpios);
#endif

/* GPIOのON/OFFだけなので中間色は作れない。赤+緑=橙 を使う */
enum arare_led_color { COLOR_OFF, COLOR_GREEN, COLOR_AMBER, COLOR_RED };

#define BLINK_ON_MS 120
#define BLINK_OFF_MS 200

static uint8_t last_soc;
static bool have_soc;
static bool ready;

static struct k_work_delayable blink_work;
static struct k_work_delayable glance_work;
static struct k_work_delayable warn_work;

static enum arare_led_color blink_color;
static int blink_steps_left;
static bool blink_lit;

static void led_apply(enum arare_led_color c) {
    if (!ready) {
        return;
    }
    gpio_pin_set_dt(&led_red, c == COLOR_RED || c == COLOR_AMBER);
    gpio_pin_set_dt(&led_green, c == COLOR_GREEN || c == COLOR_AMBER);
#if DT_NODE_EXISTS(LED_BLUE_NODE)
    gpio_pin_set_dt(&led_blue, 0);
#endif
}

static enum arare_led_color color_for_level(uint8_t soc) {
    if (soc >= CONFIG_ARARE_BATTERY_LED_GOOD_PCT) {
        return COLOR_GREEN;
    }
    if (soc > CONFIG_ARARE_BATTERY_LED_LOW_PCT) {
        return COLOR_AMBER;
    }
    return COLOR_RED;
}

static bool usb_powered(void) {
#if IS_ENABLED(CONFIG_ZMK_USB)
    return zmk_usb_is_powered();
#else
    return false;
#endif
}

/* 何も知らせていないときの状態。USB接続中だけ点けたままにする */
static void apply_resting(void) {
    if (have_soc && usb_powered()) {
        led_apply(color_for_level(last_soc));
    } else {
        led_apply(COLOR_OFF);
    }
}

static void blink_step(struct k_work *work) {
    ARG_UNUSED(work);
    if (blink_steps_left <= 0) {
        apply_resting();
        return;
    }
    blink_lit = !blink_lit;
    led_apply(blink_lit ? blink_color : COLOR_OFF);
    blink_steps_left--;
    k_work_schedule(&blink_work, K_MSEC(blink_lit ? BLINK_ON_MS : BLINK_OFF_MS));
}

static void blink(enum arare_led_color color, int times) {
    k_work_cancel_delayable(&glance_work);
    blink_color = color;
    blink_steps_left = times * 2; /* 点灯と消灯で1往復 */
    blink_lit = false;
    k_work_reschedule(&blink_work, K_NO_WAIT);
}

static void glance_end(struct k_work *work) {
    ARG_UNUSED(work);
    apply_resting();
}

/* 現在の残量色を短く見せる */
static void glance(void) {
    if (!have_soc) {
        return;
    }
    k_work_cancel_delayable(&blink_work);
    blink_steps_left = 0;
    led_apply(color_for_level(last_soc));
    k_work_reschedule(&glance_work, K_MSEC(CONFIG_ARARE_BATTERY_LED_GLANCE_MS));
}

/* 充電を促すべき状況か。使っていないときや充電中は促さない */
static bool warning_needed(void) {
    if (!have_soc || last_soc > CONFIG_ARARE_BATTERY_LED_LOW_PCT) {
        return false;
    }
    if (usb_powered()) {
        return false;
    }
    return zmk_activity_get_state() == ZMK_ACTIVITY_ACTIVE;
}

static int warning_interval_sec(void) {
    return (last_soc <= CONFIG_ARARE_BATTERY_LED_CRITICAL_PCT)
               ? CONFIG_ARARE_BATTERY_LED_CRITICAL_INTERVAL_SEC
               : CONFIG_ARARE_BATTERY_LED_WARN_INTERVAL_SEC;
}

static void warn_fire(struct k_work *work) {
    ARG_UNUSED(work);
    if (!warning_needed()) {
        return; /* 再スケジュールしない＝警告停止 */
    }
    blink(COLOR_RED, (last_soc <= CONFIG_ARARE_BATTERY_LED_CRITICAL_PCT) ? 3 : 2);
    k_work_reschedule(&warn_work, K_SECONDS(warning_interval_sec()));
}

static void update_warning(void) {
    if (warning_needed()) {
        if (!k_work_delayable_is_pending(&warn_work)) {
            k_work_reschedule(&warn_work, K_SECONDS(warning_interval_sec()));
        }
    } else {
        k_work_cancel_delayable(&warn_work);
    }
}

static bool crossed_down(uint8_t before, uint8_t now) {
    const int low = CONFIG_ARARE_BATTERY_LED_LOW_PCT;
    const int crit = CONFIG_ARARE_BATTERY_LED_CRITICAL_PCT;
    return (before > low && now <= low) || (before > crit && now <= crit);
}

static void on_battery(uint8_t soc) {
    const bool first = !have_soc;
    const uint8_t before = last_soc;
    last_soc = soc;
    have_soc = true;

    if (first) {
        LOG_INF("arare: 電池 %u%% — 起動時の残量を表示", soc);
        glance(); /* 起動後、最初に残量が読めた時点で知らせる */
    } else if (crossed_down(before, soc)) {
        LOG_INF("arare: 電池 %u%% — 閾値を下回ったので警告", soc);
        blink(COLOR_RED, (soc <= CONFIG_ARARE_BATTERY_LED_CRITICAL_PCT) ? 3 : 2);
    } else if (blink_steps_left <= 0 && !k_work_delayable_is_pending(&glance_work)) {
        apply_resting(); /* USB接続中の色を新しい残量に追従させる */
    }
    update_warning();
}

static int arare_battery_led_listener(const zmk_event_t *eh) {
    const struct zmk_battery_state_changed *bat = as_zmk_battery_state_changed(eh);
    if (bat != NULL) {
        on_battery(bat->state_of_charge);
        return ZMK_EV_EVENT_BUBBLE;
    }

    if (as_zmk_activity_state_changed(eh) != NULL) {
        if (zmk_activity_get_state() == ZMK_ACTIVITY_ACTIVE) {
            glance(); /* 復帰したら残量を一目で示す */
        } else {
            /* 眠っている間は消しておく（点けっぱなしで電池を減らさない） */
            k_work_cancel_delayable(&blink_work);
            k_work_cancel_delayable(&glance_work);
            blink_steps_left = 0;
            led_apply(COLOR_OFF);
        }
        update_warning();
        return ZMK_EV_EVENT_BUBBLE;
    }

#if IS_ENABLED(CONFIG_ZMK_USB)
    if (as_zmk_usb_conn_state_changed(eh) != NULL) {
        if (blink_steps_left <= 0 && !k_work_delayable_is_pending(&glance_work)) {
            apply_resting();
        }
        update_warning();
        return ZMK_EV_EVENT_BUBBLE;
    }
#endif

    return ZMK_EV_EVENT_BUBBLE;
}
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

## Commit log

2026-09-01 第2次基板に合わせてZMK設定を全面書き直し
    - board: nice_nano_v2 → seeeduino_xiao_ble（両側XIAO nRF52840）
    - kscan: matrix → charlieplex 6線/片手（zmk,kscan-gpio-charlieplex、ポーリング5ms）
    左はcompositeでジョイスティック押込(D10直結)を row6 に合成
    - central = 右手（トラックボール側）。PMW3610 → PAW3222 (sekigon torabo-tsukiブランチ, spi1 3線SDIO)
    - ZMK v0.2.1 → v0.3.0、ZMK Studio対応（physical layout 47キーを基板実座標から生成）
    - transform/物理レイアウトは arare_matrix.json と .kicad_pcb から機械生成（転記なし）
    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
2026-09-01 ケース・パーツの3Dデータを model/case/ で公開（moNa2方式）
    - 発注フォルダのSTL 18点（プレート4種・ガスケット・エンコーダノブ・小物parts1-4）
    - model/README.md: 個人使用のみの注意書き＋ファイル一覧＋印刷設定の目安
    - README.md: プロジェクト紹介と公開データ一覧を追加（基板・キーキャップは非公開と明記）
    [bottom plate L.stl, bottom plate R.stl, gasket mount L.stl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]
2026-09-02 ロゴデータを model/logo/ で公開（SVGマスター・PNG・基板実寸SVG/DXF/STL）
    [arare_logo_L_16.179mm.dxf, arare_logo_L_16.179mm_emboss0.6mm.stl, arare_logo_R_13.324mm.dxf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]
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2026-09-02 重なり修正・アクリル質感最終強化・霰の背景・エンコーダ表記整理とコピペ割当
2026-09-04 レイヤーバーを上部横並びに復帰＋US/JIS配列切替＋接続画面＋ヘッダー配列表示
    - レイヤー選択を左サイドの湾曲レールから元の横並び（ボード上部）に戻す
    - ヘッダーに配列トグル（US⇄JIS）を常設。切替で全レイヤーの記号キーを
    QMK互換変換表でJIS/USホスト向けに変換（表示は出力される記号のまま・Undo可）
    - FORGE出力に配列コメントと dt-bindings/zmk/outputs.h を追加
    - DEVICESパネルを「接続」画面に刷新（DYA Studio参考）:
    ステータス（アクティブな接続/現在の配列/出力優先度）＋BT1-5カード
    （名前・キーマップ・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
2026-09-04 アイコンを追加し、カラーシミュレーターを GitHub Pages に載せる
    - docs/ に favicon.ico / arare_icon.svg / apple-touch-icon.png（ライト版）を追加し、
    index.html の <head> から参照
    - カラーシミュレーターを docs/colorsim.html として追加（アイコンはダーク版を data URI で内蔵）
    アイコンは語源「感謝感激雨あられ」から起こした「雨＋霰の粒」。
    原本とスクリプトは design-assets/icon/current/（このリポジトリ外）。
2026-09-04 colorsim: 分解図の既定カメラを写真基準(AZ23.7/EL15/D523)に、AUTOをゆっくり回転に
    - EXPLODE押下時にAZ 23.7° / EL 15.0° / フィット距離×0.85へアニメ移動
    - refit()も分解図中は同倍率(リサイズでズームが戻るのを防止)
    - ⟳AUTO: ON時にEL 15°へ移行し約60秒/周で回転(旧: 約26秒/周)
2026-09-04 firmware: レイヤーHUD用ステータスBLEアドバタイズを追加（ビルド検証）
    - prospector-zmk-module v2.2.3 (SHA固定) をwest.ymlに追加
    - 右手(central)のconfで CONFIG_ZMK_STATUS_ADVERTISEMENT=y
    - Mac常駐アプリ ArareHUD がmanufacturer dataから現在レイヤーを受信する
2026-09-04 colorsim: PROTOプリセットをユーザー確定配色に更新
    - 底面プレート #e2e4e7 → #17191c（黒）
    - トラックボール(R) #33373d → #f4f5f6（白）。プリセット値の {L,R} 左右別色に対応
    - 起動時デフォルトも同配色（貼り付けカラーコード ARARE1 と一致検証済み）
2026-09-04 studio: ArareHUD のメニューバー表示をStudioから切替できるように
    arare Studio の DEVICE TUNING に「ARARE HUD」パネルを追加し、
    常駐アプリ ArareHUD のメニューバーアイコン表示をこの画面から選べるようにした。
    - ArareHUD 側に制御サーバ（127.0.0.1:47800 限定bind）を追加
    GET /state / POST /menubar。Origin許可リスト＋Chrome PNA用ヘッダ対応
    - Studio側は起動時に静かに検出し、未起動なら再検出ボタンと起動コマンドを表示
    - ローカル接続が使えない配信元（アーティファクト等）では公開ページへ誘導
    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
2026-09-04 studio: HUDパネルにブラウザ制限を迂回する導線を追加
    ブラウザによっては https のページから 127.0.0.1 への fetch が
    ERR_BLOCKED_BY_CLIENT で遮断されるため（Claude内蔵ブラウザで実測）、
    ArareHUD 自身が配信する設定ページ（http://127.0.0.1:47800/）を開く
    ボタンを併設した。同一オリジンなのでブラウザの制限を受けない。
2026-09-05 site: 取扱説明書を特設サイトのトップにし、入場アニメを追加
    購入予定者が最初に見るページを docs/index.html に据えた。
    - index.html = 取扱説明書 ＋ 入場アニメーション「五粒（いつつぶ）」
    霰が5粒降ってきて A・R・E の3キーを叩き arare と打ち上がる 3.45秒。
    a・r・a・r・e はこの配列では全部が左手側にあり、異なるキーは3つだけ。
    盤面は arare.dtsi の47キー実座標、外形は3Dアセンブリ天板の平面シルエット。
    SVG＋Web Animations API のみ（Canvas・外部ライブラリなし）。
    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
2026-09-05 site: arare Studio をトップに戻し、取扱説明書を /manual.html に分ける
    前のコミットで Studio を studio.html へ動かしたため、これまでの
    公開URL（ルート）を開くと取扱説明書が出るようになっていた。
    Studio を元のURLに戻し、取扱説明書は独立したURLに置く。
    - / …………… arare Studio（元のURLに復帰。PAGES_URL もルートへ戻す）
    - /manual.html … 取扱説明書 ＋ 入場アニメーション
    - /colorsim.html … カラーシミュレーター
    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
2026-09-05 site: 取扱説明書の noscript フォールバックが統合時に落ちていたのを修正
    入場アニメ側の <noscript> は <div id=\"arare-intro\"> の直前にあり、
    build_site.py の本体抽出（div 始まり）から漏れていた。
    JS が無効・失敗したときに 9 秒の CSS フェイルセーフを待たず
    本文へ到達できるようにする。
2026-09-05 site: 入場をゆっくりにし、リセット／ライトの穴を図に入れ、表題欄をロゴに
    - 入場アニメを 3.45s → 4.6s（再生レート 0.75）。ウォッチドッグ 9.5s、
    CSS フェイルセーフ 12s も合わせて伸ばした
    - リセットスイッチとライトの穴を、入場アニメと Fig.1 に追加。
    天板シルエットの実測で左右4か所とも Ø1.86 の同寸
    - Fig.2 の平面図で穴が別サイズに見えていたのは、片方に内部部品 part2 が
    重なっていたため。part2 を描画対象から外し、穴は天板の実輪郭に任せる
    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
2026-09-05 manual: Fig.1 をケース外形にし、穴のずれを解消。スティックの意図を追記
    - Fig.1 が基板(PCB)の外形を描いていたため、ケース天板の座標にある
    リセット・ライトの穴が基板の外にはみ出していた。
    外形をケース天板の平面シルエット（122.5 × 96.4 mm）に差し替えて解消。
    購入者が手にするのはケースなので、サイズ感もケース基準になる。
    - スティックを載せた理由を 01 コンセプトと各部の表に明記。
    トラックパッドの 2本指・3本指の直感的な操作を、親指ひとつで
    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
2026-09-05 manual: 右手側の穴の座標を修正（15mmずれていた）／残量の確認方法を追記
    - Fig.1 の右手側の穴を pcb_x - 14.975 + 125.645 で置いていたが、
    右手の変換は pcb_x + 125.645（sheet.py の OFF["R"] と同じ）。
    余計に 14.975 引いていて 15mm 左にずれ、ケース左端にはみ出していた。
    153.06 / 164.57 に修正。ホイール(34.75→160.40)・USB-C(33.293→158.94)・
    タクトSW(116.08→241.73) で変換を検算し、左右とも USB-C を
    -5.9 / +5.6 mm で挟む対称配置になることを確認した。
    - 「はじめかた」の充電の項に残量の確認方法を追記。
    報告は左右とも有効で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
2026-09-05 firmware: 電池残量をマイコンのLEDで知らせる
    XIAO nRF52840 内蔵のRGB LEDで残量を色で示す。常時点灯はせず、
    知らせるべきときだけ光らせる。
    - 起動して最初に残量が読めたとき / スリープ復帰時 … 残量色を1.5秒点灯
    - 残量が閾値を下回った瞬間 … その場で赤く点滅
    - 残量20%以下 … 使用中に限り5分ごとに赤2回点滅（10%以下は2分ごとに3回）
    - USB接続中 … 残量色を点灯したまま（充電の進みが分かる）
    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
2026-09-05 Revert "verify: 意図的なコンパイルエラー（このコミットは戻す）"
    This reverts commit 566f1edd9a93b5fb0cd0367ae3c6aadb213847b3.
    [battery_led.c]
2026-09-05 manual: 電池残量LEDの見かたを追記（実装済みだったのに未実装と書いていた）
    10296ab で入った CONFIG_ARARE_BATTERY_LED の挙動を、
    「はじめかた」に「ランプの見かた」として起こした。
    - 色: 緑 60%以上 / 橙 20〜60% / 赤 20%以下
    - 光るとき: 電源投入時と復帰時に1.5秒 ／ 20%割れで赤2回・以降5分ごと ／
    10%割れで赤3回・以降2分ごと ／ USB接続中は残量色を点灯したまま
    - 眠っているあいだと充電中は催促しない
    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
2026-09-05 studio: トラックボールの描画位置を実基板に合わせる
    ボードイラストのボールが実際より約17.7mm（ちょうど1キー分）左にずれていた。
    ケース設計のボール中心 KiCad(92.9, 88.2)mm を、キースイッチの実座標から
    求めた変換 units=(mm-offset)*100/17（右基板 offset=(-93.126, 17.027)mm、
    回転なしキー20個でフィット・残差0.2mm以下）で写して (1094, 419) に修正。
    半径も実寸に合わせた: 外側の破線=ボールø25(r=73.5)、内側=カップ底開口ø17.2(r=50.6)。
    エンコーダ(562/752,219)とジョイスティック(SW46中心=590,443)は
    既に実座標と一致していたため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
2026-09-05 site: 取扱説明書のアイコンを紫地（accent）版にする
    3ページで別々の版を使う取り決めに合わせた。
    Studio … ライト版（白地／黒い粒／紫の雨） 変更なし
    取扱説明書 … 紫地版（紫地／白い粒／黒い雨） ← Studio と同じライト版を見ていた
    COLOR SIMULATOR … ダーク版（黒地／白い粒／紫の雨） 変更なし（data URI で内蔵）
    favicon_accent.ico は 48px を base に 16/32 を append して作成
    （sizes 指定だと元画像以下に切り捨てられるため）。
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2026-09-05 studio: トラックボールを現行の19.1mmデータに修正（直前の修正が古い版だった）
    直前のコミット(d37a07b)はケース設計ノート2026-07-09のv1（ボールø25・中心(92.9,88.2)）に
    基づいていたが、その後ボールは25mm→19mmに変更されており、値が古かった。
    現行の正データは 3Dモデル由来の ~/arare/tools/colorsim/arare_data.json:
    trackball center=[88.5,-91.5,3.4]（3D系のY符号。KiCadでは +91.5）／bbox 19.1mm角
    これは取扱説明書(manual.html)のFig.1が使っているデータと同じで、両アプリの表示が揃う。
    座標系の一致は enc_wheel で検算（arare_data.json (34.75,-5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
2026-09-05 studio: エンコーダーに画面の拡大/縮小を追加＋JIS変換の穴を修正
    エンコーダーの回転割当に「拡大/縮小」を2種類追加した。
    Mac : &inc_dec_kp LG(EQUAL) LG(MINUS)
    Win : &inc_dec_kp LC(EQUAL) LC(MINUS)
    あわせて、この割当がJIS配列で正しく動くように配列切替の穴を2つ塞いだ。
    1. 修飾つきキーコードが変換されていなかった
    jisKey/usKey が丸ごと一致しか見ておらず、LG(EQUAL) のような形が素通りしていた。
    丸ごと一致を優先しつつ、無ければ修飾を剥いて再帰するようにした
    （LS(MINUS)→EQUAL の逆引きを壊さないための順序）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
2026-09-05 firmware: oversampling=0の電池ドライバ（検証用に有効化）
    ZMK本家をforkせずに済ませるため、設定リポジトリ側に電池ドライバを持つ。
    本家 battery_voltage_divider.c の複製で、実質の差分は oversampling 4→0 のみ。
    前回の検証が3ターゲットとも落ちた原因は、バインディングYAMLの description に
    引用符なしで ": " を含めていたためのYAML構文エラー。Zephyrは全ビルドで全バインディングを
    走査するので、1ファイルの不正で無関係な settings_reset まで落ちていた。→ クォートして修正。
    この検証コミットでは arare_L.overlay の #include を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
    [battery_voltage_divider_arare.c]
2026-09-05 Revert "verify: 意図的なコンパイルエラー（このコミットは戻す）"
    This reverts commit 73049c1d8a9294d7f6c52f3ef50a70a24cef5d83.
    [battery_voltage_divider_arare.c]
2026-09-05 firmware: SAADC差し替えを既定OFFに戻す（mainに入れる最終形）
    検証済み:
    - 有効化した状態で3ターゲットとも成功
    - わざと #error を入れた回で arare_L のみ失敗、arare_R と settings_reset は成功
    → 自前ドライバが左手のファームに実際に組み込まれ、不要な対象では除外されることを確認
    - battery.c は DEVICE_DT_GET(DT_CHOSEN(zmk_battery)) を使うため、リンクが通った時点で
    chosen が arare 版を指し、arare 版がデバイスを提供していることも証明される
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2026-09-05 Revert "verify: ジョイスティック経路の有効性を確認（このコミットは戻す）"
    This reverts commit 58a9732929f2294708e8ff15a0d96fce718bd46d.
    [battery_led.c]
2026-09-05 入場アニメ: ホイールが枠の中心に収まるよう修正
    フィナーレのアニメーションが .roll でホイール本体ごと包んで
    translateY(-15px) していたため、再生後（および ?entry=still）で
    ホイールが枠の中心から 2.55mm 上にずれたまま残っていた。
    - ホイール本体（角丸長方形）を .roll の外に出して動かさない
    - 溝線だけを clipPath で切り抜いて転がす
    - 回転量を溝1ピッチぶん（-12.63）にして終端が初期状態と一致するように
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2026-09-05 入場アニメ: 2回目以降の短縮版を廃止し、常に同じ長さで再生する
    何度目の訪問でも 3.52秒・語源の行つきで統一する。
    - mode 判定から short を削除（entry パラメータの short も廃止）
    - 再生レートを 0.98 の一本に
    - 「見たかどうか」の localStorage 記録をやめた（読み手がいなくなったため、
    書き込みと「入場をもう一度」ボタンの removeItem も削除）
    prefers-reduced-motion の still と、目次直リンク・非表示タブの off は
    訪問回数とは無関係なので残す。
2026-09-06 firmware: ジョイスティックにトラックパッドの3本指相当を割り当て
    スティックを倒した方向でmacOSの既定ショートカットを送る:
    上=⌃↑(Mission Control) / 下=⌃↓(App Exposé) / 左右=⌃←⌃→(スペース移動)
    ZMK標準の zmk,input-processor-behaviors では実現できないため自前で実装した。
    あちらは zmk_behavior_invoke_binding の第3引数が bool pressed で、移動量が
    真偽値に潰れて左右の区別が消え、ドライバが値0を報告しないため解放もされない。
    - dts/bindings/input_processor/arare,input-processor-gesture.yaml
    - src/input_processor_gesture.c
    相対移動を軸ごと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
2026-09-06 Revert "verify: ジェスチャ経路の有効性を確認（このコミットは戻す）"
    This reverts commit 543b7637d5cd15feed347071780507bfdfb76c27.
    [battery_led.c]
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2026-09-06 studio: キー割当を「実際に押して設定」できるようにした
    KEY EDIT に「⌨ 押して設定」を追加。押すと待機状態になり、次に叩いた
    キーの組み合わせ（⇧⌃⌥⌘込み）がそのまま割当になる。中止は Esc。
    - KeyboardEvent.code を使う。これは「キーの物理位置」でOSの配列設定に
    左右されないため、ZMKの &kp が送るスキャンコードとそのまま対応する。
    よってJIS変換は掛けない（JISで「=」を出したい人は実際にその打ち方をすればよい）
    - capture:true で先に受け取り preventDefault + stopPropagation。
    既存の ⌘Z(undo) ハンドラや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
2026-09-06 studio: タクトSWのランチャーと、ジョイスティックのレイヤー別設定を追加
    LAUNCHER パネル（タクトSWでアプリ/URLを開く）:
    - キーボード自身はアプリを開けないので、F13〜F16 を送り Mac 側で結びつける二段構え
    - 4つのタクトSWごとに「そのまま/アプリを開く/URLを開く」と対象を指定
    - 選ぶと L0 のキーマップを自動で書き換える（そのままなら出荷時の割当へ戻す）
    - Mac側の手順を2通り提示。ショートカット.app（追加インストール不要）と、
    Karabiner-Elements 用のJSONをその場で生成してコピーできる形
    - RESET / UNLOCK を全部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
2026-09-06 studio+firmware: 選択制3か所のビルド構成に追従できるように
    arare はエンコーダ/ジョイスティックの代わりに普通のキースイッチを挿せる
    （ミドルプレートも構成に合わせて選べる）。Studio でその構成を宣言すると、
    表示・設定パネル・生成ファイルがまとめて追従する。
    Studio:
    - BUILD パネルを追加。左エンコーダ/右エンコーダ/ジョイスティックの3か所を
    「付けている / 普通のキー」で宣言する
    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
    [bottom plate L.stl, bottom plate R.stl, parts 1.stl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]
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2026-09-07 keymap: 出荷時キーマップを4レイヤー構成に更新
    arare Studio で作った設定をそのまま出荷時の既定にする。
    - レイヤーを3→4に（L3 は全 &trans の空きレイヤー）
    - 親指: SPACE と mo 1 を入れ替え、スティック押込(POS39)を &mo 3 に
    - タクトSW4か所を sys_reset/studio_unlock から
    BT_SEL 0/1/2 + studio_unlock へ
    - エンコーダーをレイヤー別に:
    L0/L1 = ⌘+ / ⌘− と PgUp/PgDn、L2 = 輝度 と 音量、L3 = 割当なし
    Studio 側も同じ内容を出荷時データにした。SHIPPED に sensorsL を足し、
    load()/resetAll() で encL に流し込む。LAUNCHER の「そのまま」ラベルと
    警告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
2026-09-21 fix: ジョイスティックのドライバをループの不具合を直したフォークに切り替え
    左右が繋がらない原因を追った結果、左手のジョイスティックを外すと 20/20 で繋がり、
    電池計測だけを外しても（E1）繋がらなかった。ADC の取り合いではなく、
    ジョイスティックのドライバ自体が原因。
    badjeff/zmk-analog-input-driver の analog_input.c にある
    for (uint8_t i = config->io_channels_len - 1; i >= 0; i--)
    は i が符号なしなので i >= 0 が常に真になる。全チャネルが前回と同じとき
    （スティックが静止している普通の状態）に 0→255 と巻き戻っ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
2026-09-21 fix: 右手の入力スレッドのスタックを 2048B に増やす
    左手のジョイスティック入力が届くと右手が止まる。右手の実バイナリで input スレッドの
    スタックが 0x200（512B）なのを確認した（左手は 0x400）。ZMK は split の peripheral だけ
    1024B に上げていて、central は Zephyr 既定の 512B のまま。
    arare の joy_gesture は input スレッドから &kp を呼ぶので、キー処理 → HID → USB 送信まで
    呼び出しが深くなり 512B をあふれる。直下の BT RX スレッドのスタックを壊して HardFault →
    既定の fatal ハンドラで停止する。USB のプルアップは残るので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
2026-09-21 fix: ジョイスティックを実測値で校正し、ジェスチャを「はじいたら1回」にする
    - 中点を実測値へ（AIN2 2264 mV / AIN3 1768 mV）。仮置きの 1650 のままだと
    AIN2 が常に +600 mV 倒れている扱いになり、触らなくてもジェスチャが連発していた
    - 実機の軸は想定から90°回っていた（AIN2=奥・手前、AIN3=左・右）。
    input-code を入れ替え、左右は invert
    - 実測値は Studio の再生成で消えないよう arare_L.overlay に置き、
    arare_tuning_L.dtsi は Studio が出す形（mv-deadzone のみ）に揃える
    - ジェスチャは中央へ戻るまで次を出さない。倒し続ける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
2026-09-21 fix: ジェスチャの取りこぼし・中点ずれ・斜め判定を直す（レビュー指摘）
    実測ログをドライバの計算から再現したシミュレーションで確認:
    - reset-ms 200 → 100。素早く続けてはじくと17回中9回を取りこぼしていた（→17回すべて）
    - |値| が min-value（既定6）以下のイベントは無視する。中点が一定量ずれると
    1回誤発火したあとスティックが効かなくなっていた（±250mV のずれでも4方向とも正常に）
    - 向きの判定をレポートの区切り（sync）でだけ行う。AIN2(REL_Y) が先に届くため斜めが上下に寄っていた
    - 状態を全インス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
2026-09-22 fix: 左ノブの向きと分解能を実測に合わせる
    - はんだ不良（B 相、付け直し後は C）を直したあと、診断ファームのログで確認:
    上から見て時計回りで負の向き（縮小）になっていたので、A と B を入れ替える
    - この EC12 は1クリックで4回変化する。steps=12 だと1クリックで約3回出ていたので、
    triggers-per-rotation=10 に合わせて steps=40（1クリック＝1回）
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
